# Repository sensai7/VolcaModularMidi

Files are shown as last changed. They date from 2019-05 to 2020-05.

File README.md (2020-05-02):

# VolcaModularMidi
This is a hardware mod to add MIDI IN capability to the [Korg Volca Modular](https://www.korg.com/us/products/dj/volca_modular/)

Board

## Schematic

Board

## Bill Of Materials:
 * R1  220 ohm resistor
 * R2  270 ohm resistor
 * D1  1N4148 diode
 * J1  2.54mm header
 * J2  DIN-5 connector
 * U1  6n139 optocoupler (6n138 and 6n137 should also work as well)

## How to install:

BEFORE YOU BEGIN: 

* This installation process requires you to open your Korg volca Modular, most likely voiding the warranty. The creator of this mod and all the contributors of this project are not to be held responsible for possible malfunctions caused by this process.

* In these example photos the mod was already installed (the red/orange/yellow/green cables), but I repeated the process to take the photos and make it easier to explain.

* Read the tutorial and make sure you understand all the steps before proceeding.

Be sure to have the following tools:
  * M3 screwdriver
  * Flat screwdriver (not absolutely necessary but it's useful to unplug the ribbon connectors)
  * Pliers or something to snip and cut thin cables
  * A dril or any tool to open a hole in the case

1-	Unscrew the screws from the back.
Board

2-	Gently pull from a potentiometer to detach the blue case from the circuit.
Board

3-	Unplug the batteries connector (red/black cables) in the top right of the board
Board

4-	Lay the circuit down, be careful with the speaker connection (orange/brown cables)
Board

5-	You can see the holes now, they're labelled as MIDI_RX, MIDI_TX, +3.3V, GND
Board

6-	Unpeel the black tape and unplug the keyboard connector (white/orange cables)
Board
Board

7-	Unscrew the 6 screws attaching the main board with the keyboard board.
Board

8-	Sit the main board on it's place in the blue case and open a hole on the right side enough to let the four cables go through. Then solder the four cables facing down and snip the excess wire. (disregard the quality of mine, I don't have the tools nor skill for these things :( )
Board

9-	Repeat the process from steps 7 to 1 in inverse order to reassemble the unit.

## Mod mods

If you have the tools, and patience, you can glue the female connections to the case so you can plug it directly (here's a poorly photoshopped concept illustrating it)
Board

If you prefer to use a 3.5mm stereo jack instead of the big DIN-5 connector, here's another poorly photoshopped concept
Board

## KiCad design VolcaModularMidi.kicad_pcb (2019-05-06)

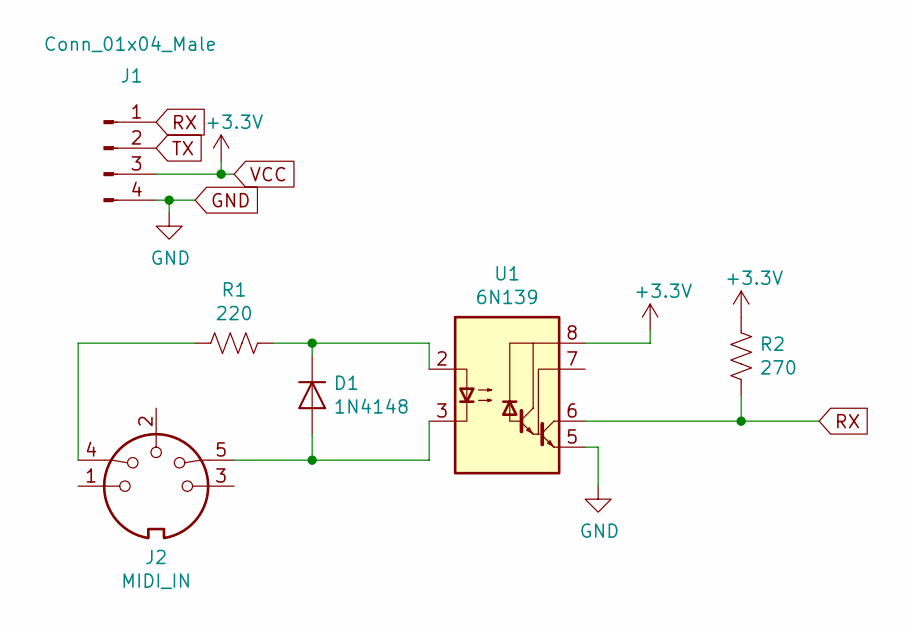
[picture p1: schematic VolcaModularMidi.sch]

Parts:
D1: 1N4148; D_DO-35_SOD27_P7.62mm_Horizontal
J1: Conn_01x04_Male; PinHeader_1x04_P2.54mm_Vertical
J2: MIDI_IN; din-5
R1: 220; R_Axial_DIN0207_L6.3mm_D2.5mm_P7.62mm_Horizontal
R2: 270; R_Axial_DIN0207_L6.3mm_D2.5mm_P7.62mm_Horizontal
U1: 6N139; DIP-8_W7.62mm

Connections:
GND: J1.4, U1.5 (GND)
unnamed: D1.1 (K), R1.1, U1.2 (C1)
unnamed: D1.2 (A), J2.5, U1.3 (C2)
unnamed: J2.4, R1.2
RX: J1.1, R2.2, U1.6 (VO2)
TX: J1.2
VCC: J1.3, R2.1, U1.8 (VCC)

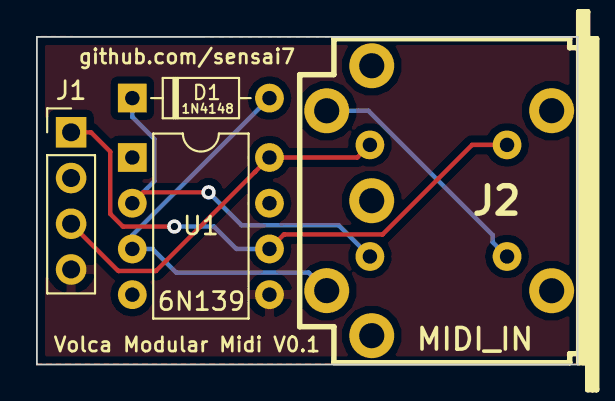
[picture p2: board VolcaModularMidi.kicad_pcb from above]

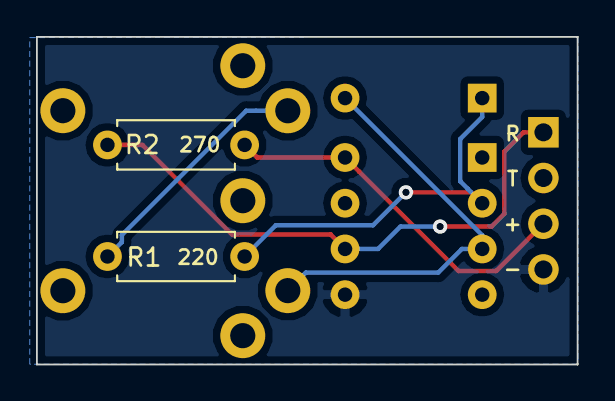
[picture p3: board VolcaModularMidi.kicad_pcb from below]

Board: 2 copper layers, 30.0 x 18.2 mm, 6 parts (2 on the bottom side), 6 nets.

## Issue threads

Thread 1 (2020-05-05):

Stereo jack type A wiring

spongefile, 2020-05-05:
For people doing the 3.5mm stereo jack mod, MIDI type A (used by both Korg and the OP-Z OPlab) is the crossed-bridge connection, not the parallel connection. (The photoshop diagram has these reversed)

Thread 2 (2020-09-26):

part number for DIN-5 MIDI connector?

chronopoulos, 2020-09-26:
can you share the part number for the MIDI connector you used on this board? different parts have different footprints.

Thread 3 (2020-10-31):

source files available?

onewheeltom, 2020-10-31:
I would use the 3.5mm jack so that the mod is internal. I see on Tindie that you are no longer selling the boards. If new boards need to be made, I might as well change the jack mounting. To do that I would have to edit the original files. Are they available?

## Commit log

2019-05-06 Version 0.1 finished
    [VolcaModularMidi-B.Cu.gbr, VolcaModularMidi-B.Mask.gbr, VolcaModularMidi-B.Paste.gbr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]
2019-05-06 adjusted silkscreen
    [VolcaModularMidi-B.Cu.gbr, VolcaModularMidi-B.Mask.gbr, VolcaModularMidi-B.Paste.gbr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]
2020-05-02 Added Schematic
